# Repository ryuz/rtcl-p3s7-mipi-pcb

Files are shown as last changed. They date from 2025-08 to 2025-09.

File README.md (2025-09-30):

English version: [README_en.md](README_en.md)

# グローバルシャッターMIPI高速度カメラ(PYTHON300 + Spartan7)

## 概要

[こちら](https://rtc-lab.com/products/rtcl-cam-p3s7-mipi/)で紹介しておりますグローバルシャッターMIPI高速度カメラの KiCAD による設計データです。

オンセミコンダクター社 [PYTHON300イメージセンサー](https://www.onsemi.jp/products/sensors/image-sensors/python300) と AMD(Xilinx) の [Spartan7](https://www.amd.com/ja/products/adaptive-socs-and-fpgas/fpga/spartan-7.html) FPGA を用いた研究開発向けの小型のカメラモジュールです。

データシート上は VGA サイズながら 815fps の高速度撮影が可能と記載されているセンサーを利用しており、当方では [KV260](https://www.amd.com/ja/products/system-on-modules/kria/k26/kv260-vision-starter-kit.html) と [Zybo Z7](https://digilent.com/shop/zybo-z7-zynq-7000-arm-fpga-soc-development-board/) に接続して 320x320 サイズで 1000fps 撮像が出来ております。

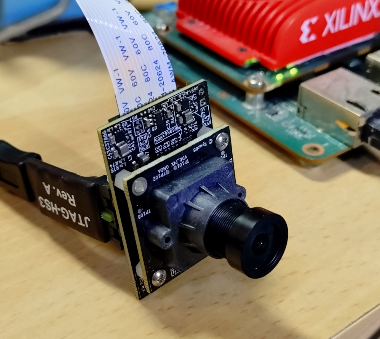
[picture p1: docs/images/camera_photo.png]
カメラ外観写真


撮影動画なども[こちら](https://rtc-lab.com/products/rtcl-cam-p3s7-mipi/)で紹介しております。

## 回路図

回路図は以下です。

- [イメージセンサー子基板](sensor_python300/sensor_python300.pdf)
- [FPGA親基板](mipi_spartan7/mipi_spartan7.pdf)

## 基板販売

当方で製造したものを[BOOTH](https://rtc-lab.booth.pm/)にて販売中です。

- [モノクロ版](https://rtc-lab.booth.pm/items/7427869)
- [カラー版](https://rtc-lab.booth.pm/items/7428802)

## 関連ソフトウェア

現時点では、KV260 に独自仕様でデータを送るプロジェクトがあります。

- [Spartan-7 のデザイン](https://github.com/ryuz/rtcl-designs/tree/main/projects/rtcl_p3s7_mipi/rtcl_p3s7_mipi)
- [KV260 の デザイン](https://github.com/ryuz/rtcl-designs/tree/main/projects/kv260/kv260_rtcl_p3s7_hs)

他に速度を落として ZYBO と接続できる事や、MIPI-CSI に準拠することも可能なことを確認していますが、まだプロジェクトとして準備できておりませんので今後にご期待ください。

## リポジトリ構成

| ディレクトリ |  説明 |
|:---|:---|
| mipi_spartan7 | Spartan7 FPGA の載った親基板のプロジェクト |
| sensor_python300 | PYTHON300 イメージセンサーの載った子基板のプロジェクト |
| sensor_mipi | 親子基板を共取り製造用に結合したプロジェクト |

## 免責事項

本設計データは、研究開発用の試作実験に用するものであり、利用に際して発生した如何なる損害も作者は補償いたしませんので予めご了承ください。

## ライセンス(License)

本設計データは、[クリエイティブ・コモンズ 表示-非営利 4.0 国際 ライセンス](https://creativecommons.org/licenses/by-nc/4.0/deed.ja)の下で提供されています。

製造した本基板の無断での販売や配布を行わない限りは、趣味や研究開発用途でご自由にお使いいただく事が出来ます。

また、商用に製造販売を希望される場合は、別途ライセンス契約を作者までご相談ください。[お問い合わせフォーム](https://rtc-lab.com/contact/)などからお問い合わせ頂けます。

## 作者情報

渕上 竜司(Ryuji Fuchikami)
[リアルタイムコンピューティング研究所](https://rtc-lab.com/)

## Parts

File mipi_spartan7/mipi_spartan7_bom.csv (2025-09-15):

Reference | Value | Datasheet | Footprint | Qty | DNP
C1,C2,C3,C5,C6,C7,C10,C11,C12,C13,C15,C16,C18,C20,C51,C53,C54,C55 | 0.47uF | ~ | Capacitor_SMD:C_0402_1005Metric | 18
C4,C14,C46,C49 | 47uF | ~ | Capacitor_SMD:C_0603_1608Metric | 4
C8,C9,C17,C21,C48,C50,C52 | 4.7uF | ~ | Capacitor_SMD:C_0402_1005Metric | 7
C19,C37,C38,C39,C43,C44,C45 | 10uF | ~ | Capacitor_SMD:C_0603_1608Metric | 7
C40 | <DNP> C | ~ | Inductor_SMD:L_0402_1005Metric | 1
C41,C42 | 22pF | ~ | Inductor_SMD:L_0402_1005Metric | 2
C47 | 100uF | ~ | Capacitor_SMD:C_1206_3216Metric | 1
FL1,FL2,FL3 | DLM0NSM900HY2D | ~ | mipi_spartan7:DLM0NSM900HY2D | 3
J1 | SFW15R-1STE1LF | SFW15R-1STE1LF | mipi_spartan7:SFW15R-1STE1LF | 1
J2 | DF40C-60DP-0.4V(51) | ~ | mipi_spartan7:DF40C-60DP-0.4V51 | 1
J3 | <DNP> PIN1X2 | ~ | mipi_spartan7:PH_01x02_2.54mm_NoSilk | 1
J4 | 0878325622 | ~ | mipi_spartan7:878325622 | 1
J5 | <DNP> SSQ-106-02-F-D-RA | ~ | mipi_spartan7:PH_02x06_2.54mm | 1
L3,L4 | 2.2uH | ~ | Inductor_SMD:L_1008_2520Metric | 2
LED1,LED2 | 150060VS75000 | ~ | LED_SMD:LED_0603_1608Metric | 2
R1,R28,R29,R30,R34,R35,R50,R65,R66,R67,R68,R69,R74,R75,R76,R77,R78,R79 | 0 | ~ | Resistor_SMD:R_0402_1005Metric | 18
R2,R3,R4,R5,R6,R7 | 120_1% | ~ | Resistor_SMD:R_0402_1005Metric | 6
R8,R11,R12,R15,R16,R19 | 60.4_1% | ~ | Resistor_SMD:R_0402_1005Metric | 6
R9,R10,R13,R14,R17,R18 | 150_1% | ~ | Resistor_SMD:R_0402_1005Metric | 6
R20,R21,R23,R24,R36,R37,R49 | 100 | ~ | Resistor_SMD:R_0402_1005Metric | 7
R22 | 49.9 | ~ | Resistor_SMD:R_0402_1005Metric | 1
R25,R26 | 2.2k | ~ | Resistor_SMD:R_0402_1005Metric | 2
R27 | 1k | ~ | Resistor_SMD:R_0402_1005Metric | 1
R31,R32 | 4.7k | ~ | Resistor_SMD:R_0402_1005Metric | 2
R33 | 330 | ~ | Resistor_SMD:R_0402_1005Metric | 1
R38,R39,R40,R41,R42,R43,R44,R45,R46 | 100_1% | ~ | Resistor_SMD:R_0402_1005Metric | 9
R47,R48 | <DNP> R | ~ | Resistor_SMD:R_0402_1005Metric | 2
R63,R64 | 10k | ~ | Resistor_SMD:R_0402_1005Metric | 2
R70 | 91k_1% | ~ | Resistor_SMD:R_0402_1005Metric | 1
R71 | 120k_1% | ~ | Resistor_SMD:R_0402_1005Metric | 1
R72 | 300k_1% | ~ | Resistor_SMD:R_0402_1005Metric | 1
R73 | 150k_1% | ~ | Resistor_SMD:R_0402_1005Metric | 1
U1 | XC7S6-2FTGB196C | XC7S6-1FTGB196C | mipi_spartan7:FTGB196 | 1
U2 | IS25LP016D-JULE-TR | http://ww1.microchip.com/downloads/en/DeviceDoc/Atmel-8707-SEEPROM-AT25010B-020B-040B-Datasheet.pdf | mipi_spartan7:IS25LP016D-JULE-TR | 1
U6,U7 | AP3401DNTR-G1 |  | mipi_spartan7:Diodes_UDFN2020-6_Type-J | 2
U8 | TPS22918DBV | http://www.ti.com/lit/ds/symlink/tps22917.pdf | Package_TO_SOT_SMD:SOT-23-6 | 1
X1 | SG-210STF 50.0000ML5 | https://support.epson.biz/td/api/doc_check.php?dl=brief_SG5032CAN&lang=en | Oscillator:Oscillator_SMD_SeikoEpson_SG8002LB-4Pin_5.0x3.2mm | 1
X2 | SG-210STF 72.0000ML0 | https://support.epson.biz/td/api/doc_check.php?dl=brief_SG5032CAN&lang=en | Oscillator:Oscillator_SMD_SeikoEpson_SG8002LB-4Pin_5.0x3.2mm | 1

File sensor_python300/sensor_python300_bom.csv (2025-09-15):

Reference | Value | Datasheet | Footprint | Qty | DNP
C101,C114,C116,C117 | 1uF | ~ | Capacitor_SMD:C_0402_1005Metric | 4
C102 | <DNP> C | ~ | Capacitor_SMD:C_0402_1005Metric | 1
C103,C104,C105,C106,C107,C108,C109,C110,C111,C112,C113,C119 | 0.1uF | ~ | Capacitor_SMD:C_0402_1005Metric | 12
C118,C120,C121 | 4.7uF | ~ | Capacitor_SMD:C_0402_1005Metric | 3
C122,C123,C124 | 10uF | ~ | Capacitor_SMD:C_0402_1005Metric | 3
FB101,FB102,FB103 | BLM18AG601SN1 | ~ | Inductor_SMD:L_0603_1608Metric | 3
J101 | DF40HC(4.0)-60DS-0.4V(51) | ~ | sensor_python300:DF40HC4.0-60DS-0.4V51 | 1
L102 | 2.2uH | ~ | Inductor_SMD:L_1008_2520Metric | 1
R101 | 47k | ~ | Resistor_SMD:R_0402_1005Metric | 1
R102,R123,R124,R125,R126,R127,R128,R129 | 0 | ~ | Resistor_SMD:R_0402_1005Metric | 8
R103,R107,R115,R130 | 33 | ~ | Resistor_SMD:R_0402_1005Metric | 4
R108,R110,R111,R119,R120,R121 | 1k | ~ | Resistor_SMD:R_0402_1005Metric | 6
R109,R113,R114,R116,R117,R118,R131,R132 | <DNP> R | ~ | Resistor_SMD:R_0402_1005Metric | 8
R112 | 470 | ~ | Resistor_SMD:R_0402_1005Metric | 1
R122 | 10k | ~ | Resistor_SMD:R_0402_1005Metric | 1
TP103,TP104,TP105,TP106,TP107,TP108,TP109 | ~ |  | sensor_python300:TestPin | 7
U101 | NOIP1SN0300A-QTI |  | sensor_python300:NOIP1SN1300A | 1
U102,U104 | TPS7A2033PDBVR |  | Package_TO_SOT_SMD:SOT-23-5 | 2
U103 | TPS22918DBVR | http://www.ti.com/lit/ds/symlink/tps22917.pdf | Package_TO_SOT_SMD:SOT-23-6 | 1
U105 | APX803S |  | Package_TO_SOT_SMD:SOT-23-3 | 1
U106 | TPS610995DRVR | https://www.ti.com/lit/gpn/TPS61099 | Package_SON:WSON-6-1EP_2x2mm_P0.65mm_EP1x1.6mm | 1
X101 | <DNP> DSC1103DI5-360.0000 | https://www.sitime.com/datasheet/SiT9366 | Oscillator:Oscillator_SMD_SiTime_PQFD-6L_3.2x2.5mm | 1

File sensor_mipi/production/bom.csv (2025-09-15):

Designator | Footprint | Quantity | Value | LCSC Part #
C1, C10, C11, C12, C13, C15, C16, C18, C2, C20, C3, C5, C51, C53, C54, C55, C6, C7 | 0402 | 18 | 0.47uF
C101, C114, C116, C117 | 0402 | 4 | 1uF
C102, C40 | 0402 | 2 | <DNP> C
C103, C104, C105, C106, C107, C108, C109, C110, C111, C112, C113, C119 | 0402 | 12 | 0.1uF
C118, C120, C121, C17, C21, C48, C50, C52, C8, C9 | 0402 | 10 | 4.7uF
C122, C123, C124, C19, C37, C38, C39, C43, C44, C45 | 0603 | 10 | 10uF
C14, C4, C46, C49 | 0603 | 4 | 47uF
C41, C42 | 0402 | 2 | 22pF
C47 | 1206 | 1 | 100uF
FB101, FB102, FB103 | 0603 | 3 | BLM18AG601SN1
FL1, FL2, FL3 | DLM0NSM900HY2D | 3 | DLM0NSM900HY2D | C1857796
J1 | SFW15R-1STE1LF | 1 | SFW15R-1STE1LF
J101 | DF40HC4.0-60DS-0.4V51 | 1 | DF40HC(4.0)-60DS-0.4V(51)
J2 | DF40C-60DP-0.4V51 | 1 | DF40C-60DP-0.4V(51)
J3 | PH_01x02_2.54mm_NoSilk | 1 | <DNP> PIN1X2
J4 | 878325622 | 1 | 0878325622
J5 | PH_02x06_2.54mm | 1 | <DNP> SSQ-106-02-F-D-RA
L102, L3, L4 | 1008 | 3 | 2.2uH
LED1, LED2 | 0603 | 2 | 150060VS75000
R1, R102, R123, R124, R125, R126, R127, R128, R129, R28, R29, R30, R34, R35, R50, R65, R66, R67, R68, R69, R74, R75, R76, R77, R78, R79 | 0402 | 26 | 0
R10, R13, R14, R17, R18, R9 | 0402 | 6 | 150_1%
R101 | 0402 | 1 | 47k
R103, R107, R115, R130 | 0402 | 4 | 33
R108, R110, R111, R119, R120, R121, R27 | 0402 | 7 | 1k
R109, R113, R114, R116, R117, R118, R131, R132, R47, R48 | 0402 | 10 | <DNP> R
R11, R12, R15, R16, R19, R8 | 0402 | 6 | 60.4_1%
R112 | 0402 | 1 | 470
R122, R63, R64 | 0402 | 3 | 10k
R2, R3, R4, R5, R6, R7 | 0402 | 6 | 120_1%
R20, R21, R23, R24, R36, R37, R49 | 0402 | 7 | 100
R22 | 0402 | 1 | 49.9
R25, R26, R31, R32 | 0402 | 4 | 4.7k
R33 | 0402 | 1 | 330
R38, R39, R40, R41, R42, R43, R44, R45, R46 | 0402 | 9 | 100_1%
R70 | 0402 | 1 | 91k_1%
R71 | 0402 | 1 | 120k_1%
R72 | 0402 | 1 | 300k_1%
R73 | 0402 | 1 | 150k_1%
TP103, TP104, TP105, TP106, TP107, TP108, TP109 | TestPin | 7 | ~
U1 | FTGB196 | 1 | XC7S6-2FTGB196C
U101 | NOIP1SN1300A | 1 | NOIP1SN0300A-QTI
U102, U104 | SOT-23-5 | 2 | TPS7A2033PDBVR
U103 | SOT-23-6 | 1 | TPS22918DBVR
U105 | SOT-23-3 | 1 | APX803S
U106 | WSON-6-1EP_2x2mm_P0.65mm_EP1x1.6mm | 1 | TPS610995DRVR
U2 | IS25LP016D-JULE-TR | 1 | IS25LP016D-JULE-TR
U6, U7 | Diodes_UDFN2020-6_Type-J | 2 | AP3401DNTR-G1
U8 | SOT-23-6 | 1 | TPS22918DBV
X1 | SG-210STF | 1 | SG-210STF 50.0000ML5
X101 | Oscillator_SMD_SiTime_PQFD-6L_3.2x2.5mm | 1 | <DNP> DSC1103DI5-360.0000
X2 | SG-210STF | 1 | SG-210STF 72.0000ML0

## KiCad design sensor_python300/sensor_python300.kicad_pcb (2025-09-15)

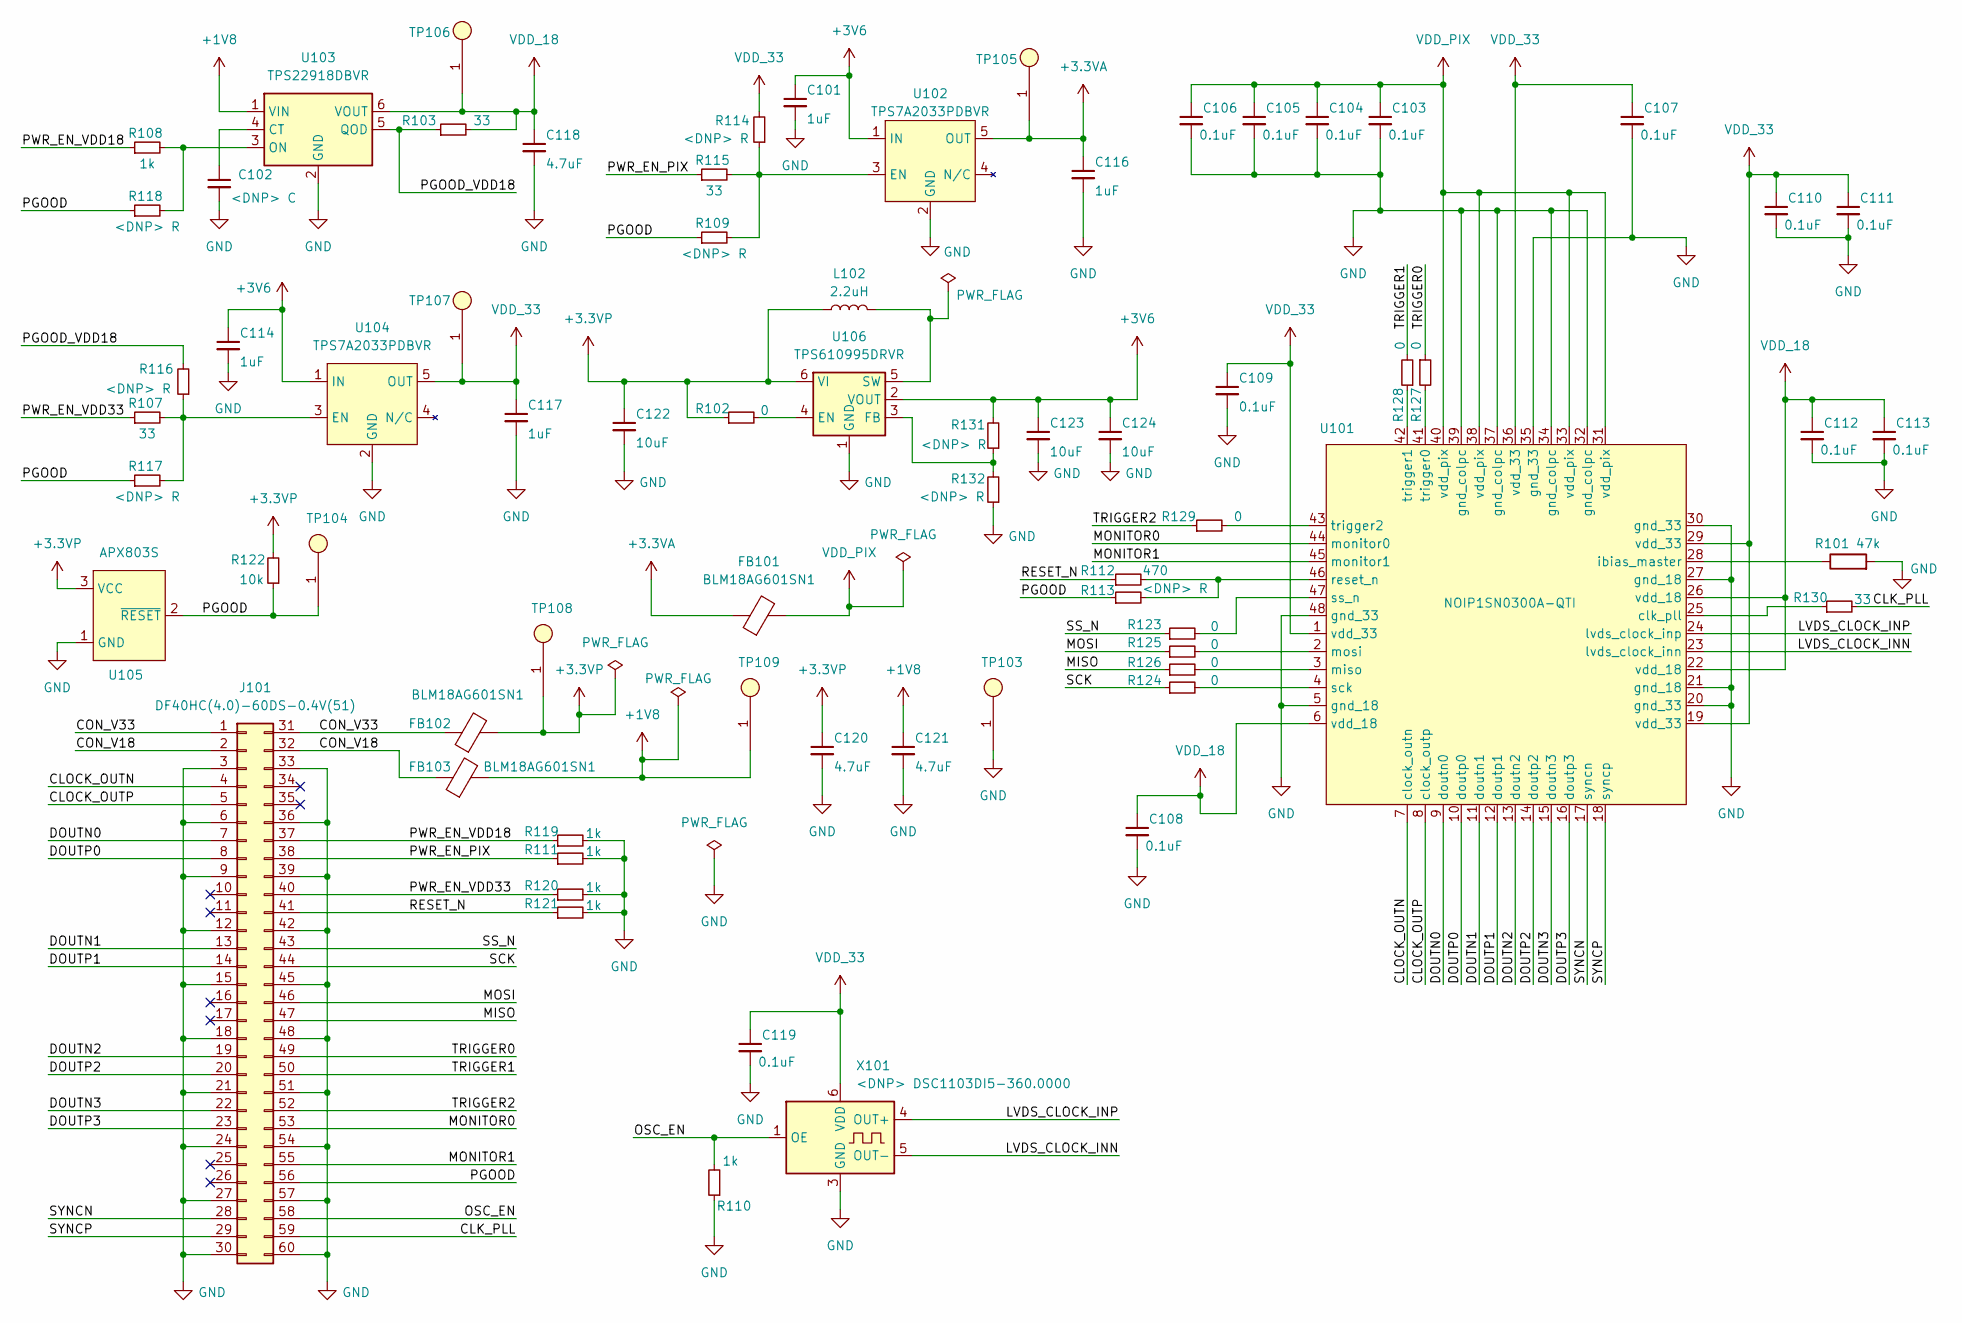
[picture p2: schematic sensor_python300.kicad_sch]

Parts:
C101, C114, C116, C117: 1uF; C_0402_1005Metric
C102: <DNP> C; C_0402_1005Metric
C103, C104, C105, C106, C107, C108, C109, C110, C111, C112, C113, C119: 0.1uF; C_0402_1005Metric
C118, C120, C121: 4.7uF; C_0402_1005Metric
C122, C123, C124: 10uF; C_0603_1608Metric
FB101, FB102, FB103: BLM18AG601SN1; L_0603_1608Metric
J101: DF40HC(4.0)-60DS-0.4V(51); DF40HC4.0-60DS-0.4V51
L102: 2.2uH; L_1008_2520Metric
R101: 47k; R_0402_1005Metric
R102, R123, R124, R125, R126, R127, R128, R129: 0; R_0402_1005Metric
R103, R107, R115, R130: 33; R_0402_1005Metric
R108, R110, R111, R119, R120, R121: 1k; R_0402_1005Metric
R109, R113, R114, R116, R117, R118, R131, R132: <DNP> R; R_0402_1005Metric
R112: 470; R_0402_1005Metric
R122: 10k; R_0402_1005Metric
TP103, TP104, TP105, TP106, TP107, TP108, TP109: TestPin
U101: NOIP1SN0300A-QTI; NOIP1SN1300A
U102, U104: TPS7A2033PDBVR; SOT-23-5
U103: TPS22918DBVR; SOT-23-6
U105: APX803S; SOT-23-3
U106: TPS610995DRVR; WSON-6-1EP_2x2mm_P0.65mm_EP1x1.6mm
X101: <DNP> DSC1103DI5-360.0000; Oscillator_SMD_SiTime_PQFD-6L_3.2x2.5mm

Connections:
+1V8: C121.1, FB103.2, TP109.1, U103.1 (VIN)
+3.3VA: C116.1, FB101.1, TP105.1, U102.5 (OUT)
+3.3VP: C120.1, C122.1, FB102.2, L102.1, R102.1, R122.2, TP108.1, U105.3 (VCC), U106.6 (VI)
+3V6: C101.1, C114.1, C123.1, C124.1, R131.2, U102.1 (IN), U104.1 (IN), U106.2 (VOUT)
/CLK_PLL: J101.59, R130.2
/CLOCK_OUTN: J101.4, U101.7 (clock_outn)
/CLOCK_OUTP: J101.5, U101.8 (clock_outp)
/CON_V18: FB103.1, J101.2, J101.32
/CON_V33: FB102.1, J101.1, J101.31
/DOUTN0: J101.7, U101.9 (doutn0)
/DOUTN1: J101.13, U101.11 (doutn1)
/DOUTN2: J101.19, U101.13 (doutn2)
/DOUTN3: J101.22, U101.15 (doutn3)
/DOUTP0: J101.8, U101.10 (doutp0)
/DOUTP1: J101.14, U101.12 (doutp1)
/DOUTP2: J101.20, U101.14 (doutp2)
/DOUTP3: J101.23, U101.16 (doutp3)
/LVDS_CLOCK_INN: U101.23 (lvds_clock_inn), X101.5 (OUT-)
/LVDS_CLOCK_INP: U101.24 (lvds_clock_inp), X101.4 (OUT+)
/MISO: J101.47, R126.1
/MONITOR0: J101.53, U101.44 (monitor0)
/MONITOR1: J101.55, U101.45 (monitor1)
/MOSI: J101.46, R125.1
/OSC_EN: J101.58, R110.2, X101.1 (OE)
/PGOOD: J101.56, R109.1, R113.1, R117.1, R118.1, R122.1, TP104.1, U105.2 (~RESET)
/PGOOD_VDD18: R103.1, R116.2, U103.5 (QOD)
/PWR_EN_PIX: J101.38, R111.1, R115.1
/PWR_EN_VDD18: J101.37, R108.1, R119.1
/PWR_EN_VDD33: J101.40, R107.1, R120.1
/RESET_N: J101.41, R112.1, R121.1
/SCK: J101.44, R124.1
/SS_N: J101.43, R123.1
/SYNCN: J101.28, U101.17 (syncn)
/SYNCP: J101.29, U101.18 (syncp)
/TRIGGER0: J101.49, R127.1
/TRIGGER1: J101.50, R128.2
/TRIGGER2: J101.52, R129.1
GND: C101.2, C102.2, C103.2, C104.2, C105.2, C106.2, C107.2, C108.2, C109.2, C110.2, C111.2, C112.2, C113.2, C114.2, C116.2, C117.2, C118.2, C119.2, C120.2, C121.2, C122.2, C123.2, C124.2, J101.3, J101.6, J101.9, J101.12, J101.15, J101.18, J101.21, J101.24, J101.27, J101.30, J101.33, J101.36, J101.39, J101.42, J101.45, J101.48, J101.51, J101.54, J101.57, J101.60, R101.2, R110.1, R111.2, R119.2, R120.2, R121.2, R132.1, TP103.1, U101.5 (gnd_18), U101.20 (gnd_33), U101.21 (gnd_18), U101.27 (gnd_18), U101.30 (gnd_33), U101.32 (gnd_colpc), U101.34 (gnd_colpc), U101.35 (gnd_33), U101.37 (gnd_colpc), U101.39 (gnd_colpc), U101.48 (gnd_33), U102.2 (GND), U103.2 (GND), U104.2 (GND), U105.1 (GND), U106.1 (GND), U106.7 (GND), X101.3 (GND)
unnamed: R130.1, U101.25 (clk_pll)
unnamed: R101.1, U101.28 (ibias_master)
unnamed: R126.2, U101.3 (miso)
unnamed: R125.2, U101.2 (mosi)
unnamed: R112.2, R113.2, U101.46 (reset_n)
unnamed: R124.2, U101.4 (sck)
unnamed: R123.2, U101.47 (ss_n)
unnamed: R127.2, U101.41 (trigger0)
unnamed: R128.1, U101.42 (trigger1)
unnamed: R129.2, U101.43 (trigger2)
unnamed: R109.2, R114.1, R115.2, U102.3 (EN)
unnamed: C102.1, U103.4 (CT)
unnamed: R108.2, R118.2, U103.3 (ON)
unnamed: R107.2, R116.1, R117.2, U104.3 (EN)
unnamed: R102.2, U106.4 (EN)
unnamed: R131.1, R132.2, U106.3 (FB)
unnamed: L102.2, U106.5 (SW)
VDD_18: C108.1, C112.1, C113.1, C118.1, R103.2, TP106.1, U101.6 (vdd_18), U101.22 (vdd_18), U101.26 (vdd_18), U103.6 (VOUT)
VDD_33: C107.1, C109.1, C110.1, C111.1, C117.1, C119.1, R114.2, TP107.1, U101.1 (vdd_33), U101.19 (vdd_33), U101.29 (vdd_33), U101.36 (vdd_33), U104.5 (OUT), X101.6 (VDD)
VDD_PIX: C103.1, C104.1, C105.1, C106.1, FB101.2, U101.31 (vdd_pix), U101.33 (vdd_pix), U101.38 (vdd_pix), U101.40 (vdd_pix)

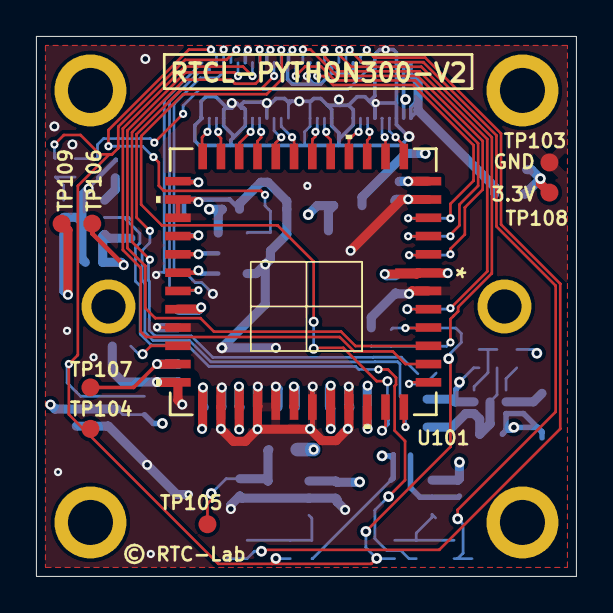
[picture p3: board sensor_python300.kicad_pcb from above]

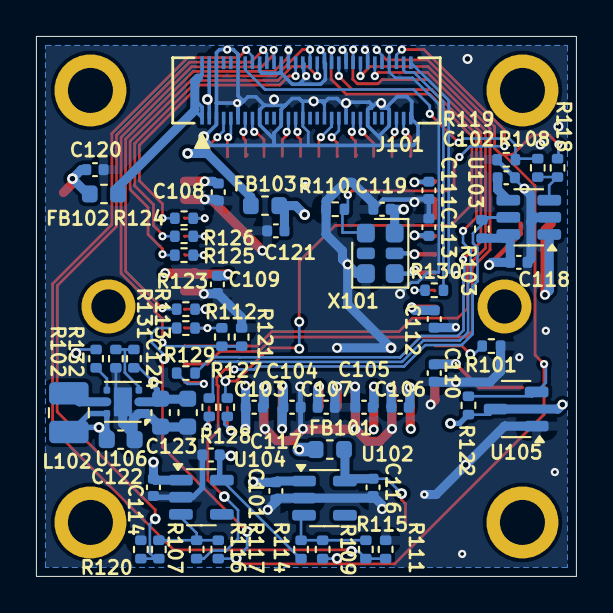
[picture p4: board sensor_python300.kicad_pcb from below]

Board: 4 copper layers, 30.0 x 30.0 mm, 71 parts (63 on the bottom side), 58 nets.

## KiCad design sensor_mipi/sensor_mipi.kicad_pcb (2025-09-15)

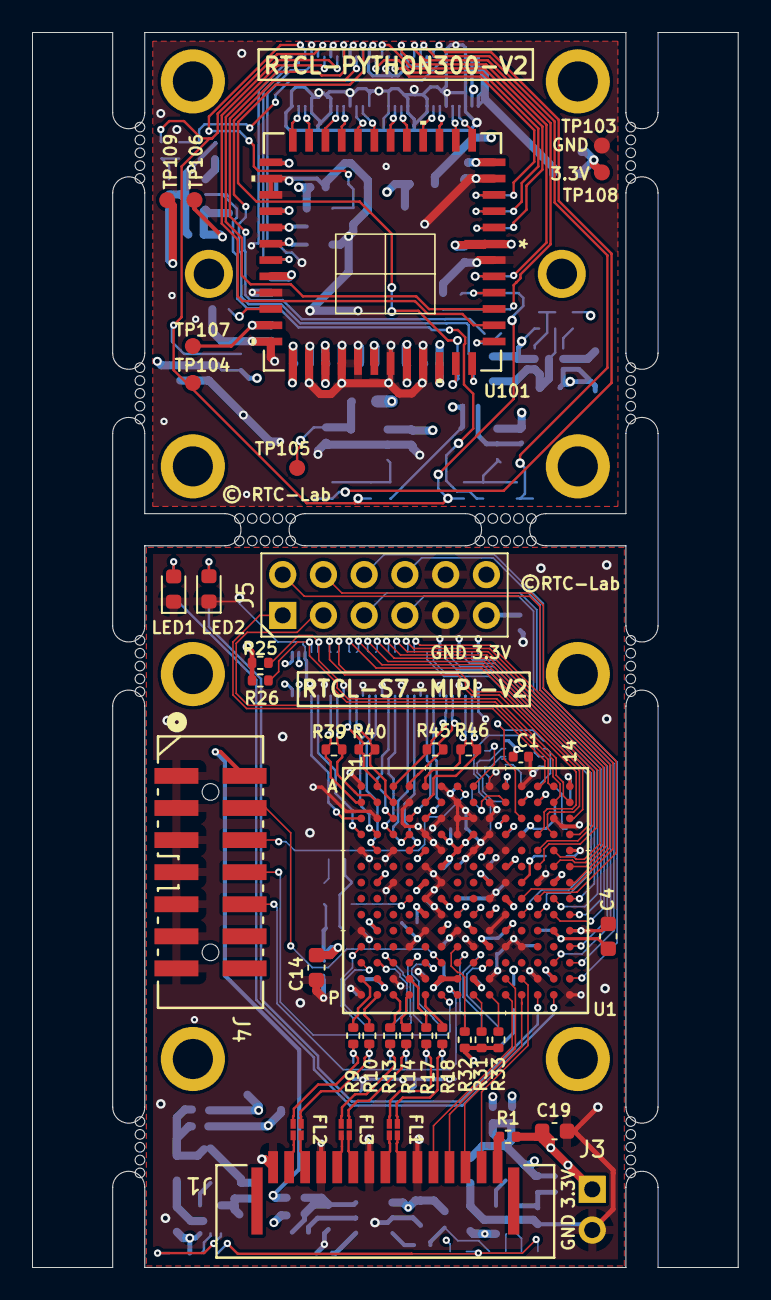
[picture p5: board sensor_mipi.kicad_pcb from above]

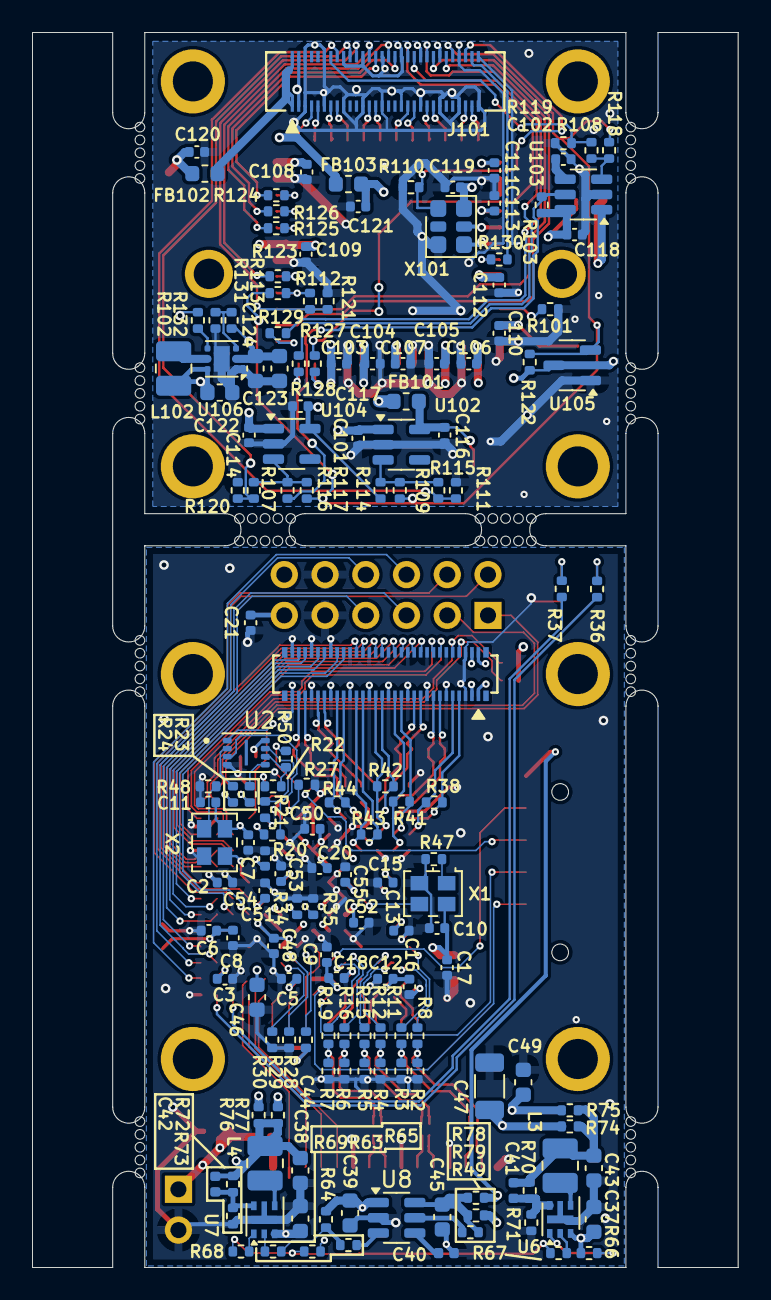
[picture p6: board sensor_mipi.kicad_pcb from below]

Board: 4 copper layers, 44.0 x 77.0 mm, 197 parts (159 on the bottom side), 185 nets.

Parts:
C1, C2, C3, C5, C6, C7, C10, C11, C12, C13, C15, C16, C18, C20, C51, C53, C54, C55: 0.47uF; C_0402_1005Metric
C4, C14, C46, C49: 47uF; C_0603_1608Metric
C8, C9, C17, C21, C48, C50, C52, C118, C120, C121: 4.7uF; C_0402_1005Metric
C19, C37, C38, C39, C43, C44, C45, C122, C123, C124: 10uF; C_0603_1608Metric
C40: <DNP> C; L_0402_1005Metric
C41, C42: 22pF; L_0402_1005Metric
C47: 100uF; C_1206_3216Metric
C101, C114, C116, C117: 1uF; C_0402_1005Metric
C102: <DNP> C; C_0402_1005Metric
C103, C104, C105, C106, C107, C108, C109, C110, C111, C112, C113, C119: 0.1uF; C_0402_1005Metric
FB101, FB102, FB103: BLM18AG601SN1; L_0603_1608Metric
FL1, FL2, FL3: DLM0NSM900HY2D
J1: SFW15R-1STE1LF
J2: DF40C-60DP-0.4V(51); DF40C-60DP-0.4V51
J3: <DNP> PIN1X2; PH_01x02_2.54mm_NoSilk
J4: 0878325622; 878325622
J5: <DNP> SSQ-106-02-F-D-RA; PH_02x06_2.54mm
J101: DF40HC(4.0)-60DS-0.4V(51); DF40HC4.0-60DS-0.4V51
L3, L4, L102: 2.2uH; L_1008_2520Metric
LED1, LED2: 150060VS75000; LED_0603_1608Metric
R1, R28, R29, R30, R34, R35, R50, R65, R66, R67, R68, R69, R74, R75, R76, R77, R78, R79, R102, R123, R124, R125, R126, R127, R128, R129: 0; R_0402_1005Metric
R2, R3, R4, R5, R6, R7: 120_1%; R_0402_1005Metric
R8, R11, R12, R15, R16, R19: 60.4_1%; R_0402_1005Metric
R9, R10, R13, R14, R17, R18: 150_1%; R_0402_1005Metric
R20, R21, R23, R24, R36, R37, R49: 100; R_0402_1005Metric
R22: 49.9; R_0402_1005Metric
R25, R26, R31, R32: 4.7k; R_0402_1005Metric
R27, R108, R110, R111, R119, R120, R121: 1k; R_0402_1005Metric
R33: 330; R_0402_1005Metric
R38, R39, R40, R41, R42, R43, R44, R45, R46: 100_1%; R_0402_1005Metric
R47, R48, R109, R113, R114, R116, R117, R118, R131, R132: <DNP> R; R_0402_1005Metric
R63, R64, R122: 10k; R_0402_1005Metric
R70: 91k_1%; R_0402_1005Metric
R71: 120k_1%; R_0402_1005Metric
R72: 300k_1%; R_0402_1005Metric
R73: 150k_1%; R_0402_1005Metric
R101: 47k; R_0402_1005Metric
R103, R107, R115, R130: 33; R_0402_1005Metric
R112: 470; R_0402_1005Metric
TP103, TP104, TP105, TP106, TP107, TP108, TP109: TestPin
U1: XC7S6-2FTGB196C; FTGB196
U2: IS25LP016D-JULE-TR
U6, U7: AP3401DNTR-G1; Diodes_UDFN2020-6_Type-J
U8: TPS22918DBV; SOT-23-6
U101: NOIP1SN0300A-QTI; NOIP1SN1300A
U102, U104: TPS7A2033PDBVR; SOT-23-5
U103: TPS22918DBVR; SOT-23-6
U105: APX803S; SOT-23-3
U106: TPS610995DRVR; WSON-6-1EP_2x2mm_P0.65mm_EP1x1.6mm
X1: SG-210STF 50.0000ML5; SG-210STF
X2: SG-210STF 72.0000ML0; SG-210STF
X101: <DNP> DSC1103DI5-360.0000; Oscillator_SMD_SiTime_PQFD-6L_3.2x2.5mm

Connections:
+1V0: C41.1, C43.1, L3.2, R70.2, R74.1, R75.1
+1V8: C42.1, C44.1, C121.1, FB103.2, J2.2, J2.32, L4.2, R72.2, R76.1, R77.1, TP109.1, U103.1 (VIN)
+3.3V: C45.1, R49.2, R78.1, R79.1, U8.6 (VOUT)
+3.3VA: C116.1, FB101.1, TP105.1, U102.5 (OUT)
+3.3VP: C19.1, C37.1, C38.1, C39.1, C120.1, C122.1, FB102.2, J2.1, J2.31, J3.1, L102.1, R1.2, R63.1, R64.1, R66.1, R102.1, R122.2, TP108.1, U6.3 (VIN), U7.3 (VIN), U8.1 (VIN), U105.3 (VCC), U106.6 (VI)
+3V6: C101.1, C114.1, C123.1, C124.1, R131.2, U102.1 (IN), U104.1 (IN), U106.2 (VOUT)
/CLK_50M: U1.H4 (IO_L13P_T2_MRCC_34), X1.3 (OUT)
/CLK_72M: U1.G11 (IO_L12P_T1_MRCC_14), X2.3 (OUT)
/CLK_N: FL1.3, J1.8 (CN)
/CLK_P: FL1.2, J1.9 (CP)
/CLK_PLL: J101.59, R130.2
/CLOCK_OUTN: J101.4, U101.7 (clock_outn)
/CLOCK_OUTP: J101.5, U101.8 (clock_outp)
/CON_V18: FB103.1, J101.2, J101.32
/CON_V33: FB102.1, J101.1, J101.31
/D0_N: FL2.3, J1.2 (DN0)
/D0_P: FL2.2, J1.3 (DP0)
/D1_N: FL3.3, J1.5 (DN1)
/D1_P: FL3.2, J1.6 (DP1)
/DOUTN0: J101.7, U101.9 (doutn0)
/DOUTN1: J101.13, U101.11 (doutn1)
/DOUTN2: J101.19, U101.13 (doutn2)
/DOUTN3: J101.22, U101.15 (doutn3)
/DOUTP0: J101.8, U101.10 (doutp0)
/DOUTP1: J101.14, U101.12 (doutp1)
/DOUTP2: J101.20, U101.14 (doutp2)
/DOUTP3: J101.23, U101.16 (doutp3)
/EMCCLK: R22.2, U1.A10 (IO_L3N_T0_DQS_EMCCLK_14)
/JTAG_TCK: J4.6, U1.A7 (TCK_0)
/JTAG_TDI: J4.10, U1.P7 (TDI_0)
/JTAG_TDO: J4.8, U1.P6 (TDO_0)
/JTAG_TMS: J4.4, U1.M6 (TMS_0)
/LED0: R36.1, U1.P13 (IO_L22N_T3_D20_14)
/LED1: R37.1, U1.P12 (IO_L22P_T3_D21_14)
/LVDS_CLOCK_INN: U101.23 (lvds_clock_inn), X101.5 (OUT-)
/LVDS_CLOCK_INP: U101.24 (lvds_clock_inp), X101.4 (OUT+)
/MIPI_CLK_HS_N: R17.2, U1.N4 (IO_L24N_T3_34)
/MIPI_CLK_HS_P: R18.2, U1.P5 (IO_L24P_T3_34)
/MIPI_CLK_LP_N: R16.2, U1.M4 (IO_L23N_T3_34)
/MIPI_CLK_LP_P: R19.2, U1.M5 (IO_L23P_T3_34)
/MIPI_D0_HS_N: R9.2, U1.N1 (IO_L20N_T3_34)
/MIPI_D0_HS_P: R10.2, U1.P2 (IO_L20P_T3_34)
/MIPI_D0_LP_N: R8.2, U1.L1 (IO_L18N_T2_34)
/MIPI_D0_LP_P: R11.2, U1.M1 (IO_L18P_T2_34)
/MIPI_D1_HS_N: R13.2, U1.P3 (IO_L21N_T3_DQS_34)
/MIPI_D1_HS_P: R14.2, U1.P4 (IO_L21P_T3_DQS_34)
/MIPI_D1_LP_N: R12.2, U1.M2 (IO_L19N_T3_VREF_34)
/MIPI_D1_LP_P: R15.2, U1.M3 (IO_L19P_T3_34)
/MISO: J101.47, R126.1
/MONITOR0: J101.53, U101.44 (monitor0)
/MONITOR1: J101.55, U101.45 (monitor1)
/MOSI: J101.46, R125.1
/OSC_EN: J101.58, R110.2, X101.1 (OE)
/PGOOD: J101.56, R109.1, R113.1, R117.1, R118.1, R122.1, TP104.1, U105.2 (~RESET)
/PGOOD_VDD18: R103.1, R116.2, U103.5 (QOD)
/PMOD0: J5.1, U1.A12 (IO_L4P_T0_D04_14)
/PMOD1: J5.3, U1.A13 (IO_L4N_T0_D05_14)
/PMOD2: J5.5, U1.M13 (IO_L15P_T2_DQS_RDWR_B_14)
/PMOD3: J5.7, U1.L14 (IO_L15N_T2_DQS_DOUT_CSO_B_14)
/PMOD4: J5.2, U1.H11 (IO_L13P_T2_MRCC_14)
/PMOD5: J5.4, U1.H12 (IO_L13N_T2_MRCC_14)
/PMOD6: J5.6, U1.N14 (IO_L21P_T3_DQS_14)
/PMOD7: J5.8, U1.M14 (IO_L21N_T3_DQS_D22_14)
/PWR_EN_PIX: J101.38, R111.1, R115.1
/PWR_EN_VDD18: J101.37, R108.1, R119.1
/PWR_EN_VDD33: J101.40, R107.1, R120.1
/QSPI_CS: U1.C11 (IO_L6P_T0_FCS_B_14), U2.1 (~CS)
/QSPI_DQ0: R23.2, U1.B11 (IO_L1P_T0_D00_MOSI_14)
/QSPI_DQ1: R24.2, U1.B12 (IO_L1N_T0_D01_DIN_14)
/QSPI_DQ2: R20.1, U1.D10 (IO_L2P_T0_D02_14)
/QSPI_DQ3: R21.1, U1.C10 (IO_L2N_T0_D03_14)
/QSPI_SCK: R50.2, U1.A8 (CCLK_0)
/RESET_N: J101.41, R112.1, R121.1
/RPI_MIPI_CLK: J1.12 (CLK), U1.N10 (IO_L23P_T3_D19_14)
/RPI_MIPI_CLK_N: FL1.4, R6.2, R16.1, R17.1
/RPI_MIPI_CLK_P: FL1.1, R7.2, R18.1, R19.1
/RPI_MIPI_D0_N: FL2.4, R2.2, R8.1, R9.1
/RPI_MIPI_D0_P: FL2.1, R3.2, R10.1, R11.1
/RPI_MIPI_D1_N: FL3.4, R4.2, R12.1, R13.1
/RPI_MIPI_D1_P: FL3.1, R5.2, R14.1, R15.1
/RPI_MIPI_GPIO: J1.11 (GPIO), U1.P10 (IO_L24P_T3_D17_14)
/RPI_MIPI_SCL: J1.13 (SCL), U1.P11 (IO_L24N_T3_D16_14)
/RPI_MIPI_SDA: J1.14 (SDA), U1.N11 (IO_L23N_T3_D18_14)
/SCK: J101.44, R124.1
/SENSOR_GPIO0: J2.37, U1.D12 (IO_L8P_T1_D11_14)
/SENSOR_GPIO1: J2.38, U1.D13 (IO_L8N_T1_D12_14)
/SENSOR_GPIO2: J2.40, U1.C14 (IO_L11N_T1_SRCC_14)
/SENSOR_GPIO3: J2.41, U1.D14 (IO_L11P_T1_SRCC_14)
/SENSOR_GPIO4: J2.43, U1.E12 (IO_L7N_T1_D10_14)
/SENSOR_GPIO5: J2.44, U1.F12 (IO_L7P_T1_D09_14)
/SENSOR_GPIO6: J2.46, U1.E13 (IO_L10N_T1_D15_14)
/SENSOR_GPIO7: J2.47, U1.F13 (IO_L10P_T1_D14_14)
/SENSOR_GPIO8: J2.49, U1.F14 (IO_L9N_T1_DQS_D13_14)
/SENSOR_GPIO9: J2.50, U1.G14 (IO_L9P_T1_DQS_14)
/SENSOR_GPIO10: J2.52, U1.J11 (IO_L17P_T2_D30_14)
/SENSOR_GPIO11: J2.53, U1.J12 (IO_L17N_T2_D29_14)
/SENSOR_GPIO12: J2.55, U1.H14 (IO_L14N_T2_SRCC_14)
/SENSOR_GPIO13: J2.56, U1.H13 (IO_L14P_T2_SRCC_14)
/SENSOR_GPIO14: J2.58, U1.J14 (IO_L18N_T2_D27_14)
/SENSOR_GPIO15: J2.59, U1.J13 (IO_L18P_T2_D28_14)
/SENSOR_LVDS_CLK_N: J2.4, R38.1, U1.C1 (IO_L11N_T1_SRCC_34)
/SENSOR_LVDS_CLK_P: J2.5, R38.2, U1.D1 (IO_L11P_T1_SRCC_34)
/SENSOR_LVDS_D0_N: J2.7, R39.1, U1.B1 (IO_L5N_T0_34)
/SENSOR_LVDS_D0_P: J2.8, R39.2, U1.B2 (IO_L5P_T0_34)
/SENSOR_LVDS_D1_N: J2.10, R40.1, U1.A2 (IO_L3N_T0_DQS_34)
/SENSOR_LVDS_D1_P: J2.11, R40.2, U1.B3 (IO_L3P_T0_DQS_34)
/SENSOR_LVDS_D2_N: J2.13, R41.1, U1.D2 (IO_L10N_T1_34)
/SENSOR_LVDS_D2_P: J2.14, R41.2, U1.E2 (IO_L10P_T1_34)
/SENSOR_LVDS_D3_N: J2.16, R42.1, U1.C3 (IO_L1N_T0_34)
/SENSOR_LVDS_D3_P: J2.17, R42.2, U1.D3 (IO_L1P_T0_34)
/SENSOR_LVDS_D4_N: J2.19, R43.1, U1.D4 (IO_L7N_T1_34)
/SENSOR_LVDS_D4_P: J2.20, R43.2, U1.E4 (IO_L7P_T1_34)
/SENSOR_LVDS_D5_N: J2.22, R44.1, U1.C4 (IO_L6N_T0_VREF_34)
/SENSOR_LVDS_D5_P: J2.23, R44.2, U1.C5 (IO_L6P_T0_34)
/SENSOR_LVDS_D6_N: J2.25, R45.1, U1.A3 (IO_L2N_T0_34)
/SENSOR_LVDS_D6_P: J2.26, R45.2, U1.A4 (IO_L2P_T0_34)
/SENSOR_LVDS_D7_N: J2.28, R46.1, U1.A5 (IO_L4N_T0_34)
/SENSOR_LVDS_D7_P: J2.29, R46.2, U1.B5 (IO_L4P_T0_34)
/SENSOR_SCL: J2.34, R26.2, U1.B13 (IO_L5P_T0_D06_14)
/SENSOR_SDA: J2.35, R25.2, U1.B14 (IO_L5N_T0_D07_14)
/SS_N: J101.43, R123.1
/SYNCN: J101.28, U101.17 (syncn)
/SYNCP: J101.29, U101.18 (syncp)
/TRIGGER0: J101.49, R127.1
/TRIGGER1: J101.50, R128.2
/TRIGGER2: J101.52, R129.1
GND: C1.2, C2.2, C3.2, C4.2, C5.2, C6.2, C7.2, C8.2, C9.2, C10.2, C11.2, C12.2, C13.2, C14.2, C15.2, C16.2, C17.2, C18.2, C19.2, C20.2, C21.2, C37.2, C38.2, C39.2, C40.2, C43.2, C44.2, C45.2, C46.2, C47.2, C48.2, C49.2, C50.2, C51.2, C52.2, C53.2, C54.2, C55.2, C101.2, C102.2, C103.2, C104.2, C105.2, C106.2, C107.2, C108.2, C109.2, C110.2, C111.2, C112.2, C113.2, C114.2, C116.2, C117.2, C118.2, C119.2, C120.2, C121.2, C122.2, C123.2, C124.2, J1.1 (GND), J1.4 (GND), J1.7 (GND), J1.10 (GND), J2.3, J2.6, J2.9, J2.12, J2.15, J2.18, J2.21, J2.24, J2.27, J2.30, J2.33, J2.36, J2.39, J2.42, J2.45, J2.48, J2.51, J2.54, J2.57, J2.60, J3.2, J4.1, J4.3, J4.5, J4.7, J4.9, J4.11, J4.13, J5.9, J5.10, J101.3, J101.6, J101.9, J101.12, J101.15, J101.18, J101.21, J101.24, J101.27, J101.30, J101.33, J101.36, J101.39, J101.42, J101.45, J101.48, J101.51, J101.54, J101.57, J101.60, LED1.1 (K), LED2.1 (K), R2.1, R3.1, R4.1, R5.1, R6.1, R7.1, R27.1, R29.1, R30.1, R34.1, R35.1, R47.1, R48.1, R71.1, R73.1, R101.2, R110.1, R111.2, R119.2, R120.2, R121.2, R132.1, TP103.1, U1.A1 (GND), U1.A6 (GND), U1.A9 (GND), U1.A11 (GND), U1.A14 (GND), U1.B4 (GND), U1.B7 (GND), U1.B9 (GND), U1.C2 (GND), U1.C6 (GND), U1.C7 (GND), U1.C8 (GND), U1.C9 (GND), U1.C13 (GND), U1.D5 (GND), U1.D7 (GND), U1.D9 (GND), U1.D11 (GND), U1.E1 (GND), U1.E3 (GND), U1.E6 (GND), U1.E8 (GND), U1.E10 (GND), U1.E14 (GND), U1.F5 (GND), U1.F9 (GND), U1.G3 (GND), U1.G6 (GND), U1.G10 (GND), U1.G12 (GND), U1.H5 (GND), U1.H9 (GND), U1.J6 (GND), U1.J10 (GND), U1.K1 (GND), U1.K5 (GND), U1.K7 (GND), U1.K9 (GND), U1.K14 (GND), U1.L4 (GND), U1.L6 (GND), U1.L8 (GND), U1.L10 (GND), U1.L11 (GND), U1.N3 (GND), U1.N5 (GND), U1.N9 (GND), U1.N12 (GND), U1.P1 (GND), U1.P14 (GND), U2.4 (GND), U6.5 (GND), U7.5 (GND), U8.2 (GND), U101.5 (gnd_18), U101.20 (gnd_33), U101.21 (gnd_18), U101.27 (gnd_18), U101.30 (gnd_33), U101.32 (gnd_colpc), U101.34 (gnd_colpc), U101.35 (gnd_33), U101.37 (gnd_colpc), U101.39 (gnd_colpc), U101.48 (gnd_33), U102.2 (GND), U103.2 (GND), U104.2 (GND), U105.1 (GND), U106.1 (GND), U106.7 (GND), X1.2 (GND), X2.2 (GND), X101.3 (GND)
unnamed: J1.15 (3V3), R1.1
unnamed: LED1.2 (A), R36.2
unnamed: LED2.2 (A), R37.2
unnamed: R63.2, R67.1, R68.1
unnamed: R64.2, R65.1, R69.1
unnamed: R33.2, U1.P9 (DONE_0)
unnamed: R35.2, U1.J7 (DXN_0)
unnamed: R34.2, U1.J8 (DXP_0)
unnamed: R31.2, U1.P8 (INIT_B_0)
unnamed: R28.2, U1.M7 (M0_0)
unnamed: R29.2, U1.M8 (M1_0)
unnamed: R30.2, U1.M9 (M2_0)
unnamed: R32.2, U1.L7 (PROGRAM_B_0)
unnamed: R27.2, U1.B10 (IO_L3P_T0_DQS_PUDC_B_14)
unnamed: R24.1, U2.2 (MISO)
unnamed: R23.1, U2.5 (MOSI)
unnamed: R22.1, R50.1, U2.6 (SCK)
unnamed: R21.2, U2.7 (~HOLD)
unnamed: R20.2, U2.3 (~WP)
unnamed: R66.2, U6.1 (EN)
unnamed: C41.2, R70.1, R71.2, U6.6 (FB)
unnamed: L3.1, U6.4 (LX)
unnamed: R67.2, U6.2 (PG)
unnamed: R68.2, U7.1 (EN)
unnamed: C42.2, R72.1, R73.2, U7.6 (FB)
unnamed: L4.1, U7.4 (LX)
unnamed: R69.2, U7.2 (PG)
unnamed: C40.1, U8.4 (CT)
unnamed: R65.2, U8.3 (ON)
unnamed: R49.1, U8.5 (QOD)
unnamed: R130.1, U101.25 (clk_pll)
unnamed: R101.1, U101.28 (ibias_master)
unnamed: R126.2, U101.3 (miso)
unnamed: R125.2, U101.2 (mosi)
unnamed: R112.2, R113.2, U101.46 (reset_n)
unnamed: R124.2, U101.4 (sck)
unnamed: R123.2, U101.47 (ss_n)
unnamed: R127.2, U101.41 (trigger0)
unnamed: R128.1, U101.42 (trigger1)
unnamed: R129.2, U101.43 (trigger2)
unnamed: R109.2, R114.1, R115.2, U102.3 (EN)
unnamed: C102.1, U103.4 (CT)
unnamed: R108.2, R118.2, U103.3 (ON)
unnamed: R107.2, R116.1, R117.2, U104.3 (EN)
unnamed: R102.2, U106.4 (EN)
unnamed: R131.1, R132.2, U106.3 (FB)
unnamed: L102.2, U106.5 (SW)
unnamed: R47.2, X1.1 (~ST)
unnamed: R48.2, X2.1 (~ST)
VCCAUX: C46.1, C48.1, C51.1, C54.1, R76.2, U1.F10 (VCCAUX), U1.H10 (VCCAUX), U1.K10 (VCCAUX), U1.L9 (VCCAUX)
VCCBRAM: C49.1, C52.1, C55.1, R75.2, U1.E5 (VCCBRAM), U1.G5 (VCCBRAM), U1.J5 (VCCBRAM)
VCCINT: C20.1, C47.1, C50.1, C53.1, R74.2, U1.D6 (VCCINT), U1.D8 (VCCINT), U1.E7 (VCCINT), U1.E9 (VCCINT), U1.F6 (VCCINT), U1.G9 (VCCINT), U1.H6 (VCCINT), U1.J9 (VCCINT), U1.K6 (VCCINT), U1.K8 (VCCINT)
VCCO_0: C5.1, C9.1, C18.1, J4.2, R28.1, R31.1, R32.1, R33.1, R78.2, U1.N6 (VCCO_0), U1.N7 (CFGBVS_0), U1.N8 (VCCO_0)
VCCO_14: C1.1, C2.1, C3.1, C4.1, C6.1, C7.1, C8.1, C11.1, C21.1, J5.11, J5.12, R25.1, R26.1, R79.2, U1.G13 (VCCO_14), U1.K13 (VCCO_14), U1.N13 (VCCO_14), U2.8 (VCC), X2.4 (VCC)
VCCO_34: C10.1, C12.1, C13.1, C14.1, C15.1, C16.1, C17.1, R77.2, U1.G2 (VCCO_34), U1.K2 (VCCO_34), U1.N2 (VCCO_34), X1.4 (VCC)
VDD_18: C108.1, C112.1, C113.1, C118.1, R103.2, TP106.1, U101.6 (vdd_18), U101.22 (vdd_18), U101.26 (vdd_18), U103.6 (VOUT)
VDD_33: C107.1, C109.1, C110.1, C111.1, C117.1, C119.1, R114.2, TP107.1, U101.1 (vdd_33), U101.19 (vdd_33), U101.29 (vdd_33), U101.36 (vdd_33), U104.5 (OUT), X101.6 (VDD)
VDD_PIX: C103.1, C104.1, C105.1, C106.1, FB101.2, U101.31 (vdd_pix), U101.33 (vdd_pix), U101.38 (vdd_pix), U101.40 (vdd_pix)

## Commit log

2025-08-03 1st commit
    [mipi_spartan7.kicad_pcb, mipi_spartan7.kicad_sch, sensor_mipi.kicad_pcb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]
2025-09-15 電源回路を昇圧DC-DCを使うものに変更
    [mipi_spartan7.kicad_pcb, mipi_spartan7.kicad_sch, mipi_spartan7_bom.csv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]
2025-09-15 生成した設計データを追加
    [bom.csv, positions.csv]
2025-09-15 Add English README and improve KiCad project error handling
2025-09-15 Add sections for board sales and related software in README
2025-09-15 Add detailed sections for board sales and related software in README
2025-09-23 Enhance README and README_en by adding details about the Zybo Z7 connection and including a link to sample videos for better clarity and information.

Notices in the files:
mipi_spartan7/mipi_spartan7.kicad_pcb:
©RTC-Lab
